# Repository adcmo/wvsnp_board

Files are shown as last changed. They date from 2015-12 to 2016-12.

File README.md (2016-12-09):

# wvsnp_board

What is it?

This is the official board schematic, files, BOM and manufacturer files for the WVSNP Reduced board.

This is the Schematic and PCB layout (including gerber files) for the WVSNP Reduced Carrier Board 
and supporting components.

License and Copyright

This is the official repository of WVSNP Project. All code, SW and Hardware contributed here is 
subject to NDA and agreements you have with the WVSNP Project and ASU.

Quick Start Guide:

NOTE- The following work was done on Ubuntu version 14. Everything should be viewable on Windows or Mac however the 3D viewer will not properly work because of the different directory structures. They will have to be manually changed in KiCAD. 

Questions or concerns: Kevin Virgen kvirgen@gmail.com

1- Download version 4.0.4 of Kicad at http://kicad-pcb.org/download/
Other versions do not work properly with the 3D viewer.

2- Download Wings 3D for 3D model creation at http://www.wings3d.com/

3- Download FreeCAd for 3D model creation at http://www.freecadweb.org/

4- Get a copy of the repository: - Using Command Prompt (Git Bash) git clone 
   //https://github.com/adcmo/wvsnp_board.git
   - Using the GitHub page While logged in to GitHub, there are URLs available 
    in the sidebar: HTTPS clone URL - Using GitHub's GUI to clone repo.

5- Once repo is copied open Kicad - Choose File -> Open Project or CTRL+o - 
   Select "WVSNP_Reduced_board_hand.kicad_pcb.pro" file

   This will open the entire project with all the files necessary to see and 
   edit the schematic and PCB layout. 

3D - To view the board in 3D drag the contents of the folder "add_these_to_packages3d"  and "custom3D" into the "/usr/share/kicad/modules/packages3d" folder.
   This may require root privileges. Then click View -> 3D viewer. If it is still not working 
   you may need to change the permission on the new files because kiCAD seems picky on them.
   Another error may be directory location. If a 3D image of a footprint is not showing up in "3D View" 
   make sure it's pointing to the correct directory by navigation to the footprint's 3D settings menu.  
	- An in Dept tutorial on how to make 3D models is located here
	https://sethkoberg.wordpress.com/2014/03/30/tutorial-custom-3d-models-for-kicad-3d-viewer/
   
6- Making Changes to schematic - Double click on "Board-To-Board.sch" inside the "schematics" folder. 
   This will open the schematic - Make any necessary changes (add/removing 
   components, adding wires, etc) - If any components were added, ensure values 
   are properly filled (see any kicad tutorials) - Once happy with your changes, 
   save it and click the "NET" icon in the tool bar and follow prompts. This step 
   ensures components are populated in PCB side of things. - Run the CvPCB tool 
   to assign footprints for your components and save changes
   - A current video of the 3D model can be seen at :
	https://www.dropbox.com/s/u4em6s6bgvm3ido/WVSNP_Reduced_board.mp4?dl=0

7- Making changes to PCB file - Double click on "WVSNP_Reduced_Board_hand.kicad_pcb" 
   - If components were added, click on "NET" on tool bar and click "Read Current 
     Netlist" This should add all the components you added to the schematic assuming 
     you have footprints available. If you don't have a footprint, look up tutorials 
     on how to create footprints. NOTE: If you assigned an existing footprint and it 
     doesn't populate, check to see if there are warnings after reading the netlist.

   - Once you finished routing all traces and placing all components, save it and run 
     "design rules check" (lady bug on tool bar).
     NOTE: Ensure that the place you are planning to have the boards manufactured 
     support your design rules. Set the design rules before making any changes.

   - Fix any issues that the checker points out. 
   - Save your changes and click "Plot" on toolbar (looks like a printer). Here you'll 
     generate your Gerbers. If you are unsure on what you'd like to add on the Gerbers, 
     look up toturials for generating Gerber files in Kicad. 

BOM

The Revision_BOM is part of the Repo (Excel file). 

Commiting Changes

Follow the same procedures as you would for any files. If using Git Bash, check which 
files have been changed with "git status" or if using GUI, see which files are showing 
in the change window.

Submitting Files for Fabrication

The zipped folder "Fab Files" have everything you need to send it for fabrication. 
Just submit the compressed folder and the shops know what to do with it. If you made 
changes, you'll need to generate new Gerber files and submit those. If you missed any 
important Gerbers (edge cuts for example) the shops will generally ask you for them

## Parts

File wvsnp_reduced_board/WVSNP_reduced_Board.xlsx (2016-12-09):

Column1 | Column2 | Column3 | Column4 | Column5 | Column6 | Column7
Id | Designator | Package | Quantity | Designation | OEM Part # | Notes
DC JACK
1 | C152 | 1206 | 1 | 22uF,±10%, | 490-4739-1-ND (http://www.digikey.com/scripts/DkSearch/dksus.dll?Detail&itemSeq=212905909&uq=636159567750798121) | ceramic
2 | C153 | 603 | 1 | 0.1uF,±10%, | 490-1532-1-ND (http://www.digikey.com/scripts/DkSearch/dksus.dll?Detail&itemSeq=212905998&uq=636159567750798121) | ceramic
3 | Zener | D44 | 1 | 5.1V 1W ±5% | DL4733A-TP (https://www.mouser.com/Search/ProductDetail.aspx)
4 | DCIN | BARREL_JACK | 1 | 2.00mm, DIP | PJ-002A (https://www.mouser.com/Search/ProductDetail.aspx?R=PJ-002Avirtualkey51780000virtualkey490-PJ-002A)
Button
1 | C162 | 603 | 1 | 1uF,±10%, | 0603ZC105KAT2A (https://www.mouser.com/Search/ProductDetail.aspx) | ceramic
2 | RESET1 | TACT SWITCH | 1 |  | PTS645SH50SMTR 92 LFS
DC-DC
1 | C163 | 805 | 1 | 4.7uF,±10%, | GRM21BR61E475KA12L (https://www.mouser.com/Search/ProductDetail.aspx) | ceramic
2 | C164 | 603 | 1 | 1000pF,±10%, | 478-1215-1-ND | ceramic
3 | C165 | 603 | 1 | 1uF,±10%, | 0603ZC105KAT2A (https://www.mouser.com/Search/ProductDetail.aspx) | ceramic
4 | R96 | 603 | 1 | 100kΩ,±1%, | CRCW0603100KFKEA (https://www.mouser.com/Search/ProductDetail.aspx) | ceramic
5 | R97 | 603 | 1 | 330Ω,±1%, | CRCW0603330RFKEA (https://www.mouser.com/Search/ProductDetail.aspx) | ceramic
6 | D1 | 603 | 1 | LED-GRN | LG Q396-PS-35 (https://www.mouser.com/Search/ProductDetail.aspx) | GRN
7 | U1 |  | 1 | MCP1727 | MCP1727-3302E/SN (https://www.mouser.com/Search/ProductDetail.aspx)
RJ45
1 | R1 | 603 | 1 | 0Ω,±5%, | CRCW06030000Z0EA (https://www.mouser.com/Search/ProductDetail.aspx)
2 | R2 | 603 | 1 | 0Ω,±5%, | CRCW06030000Z0EA (https://www.mouser.com/Search/ProductDetail.aspx)
3 | R3 | 603 | 1 | 0Ω,±5%, | CRCW06030000Z0EA (https://www.mouser.com/Search/ProductDetail.aspx)
5 | R4 | 603 | 1 | 0Ω,±5%, | CRCW06030000Z0EA (https://www.mouser.com/Search/ProductDetail.aspx)
6 | R5 | 603 | 1 | 0Ω,±5%, | CRCW06030000Z0EA (https://www.mouser.com/Search/ProductDetail.aspx)
7 | R6 | 603 | 1 | 0Ω,±5%, | CRCW06030000Z0EA (https://www.mouser.com/Search/ProductDetail.aspx)
8 | R7 | 603 | 1 | 0Ω,±5%, | CRCW06030000Z0EA (https://www.mouser.com/Search/ProductDetail.aspx)
9 | R8 | 603 | 1 | 0Ω,±5%, | CRCW06030000Z0EA (https://www.mouser.com/Search/ProductDetail.aspx)
10 | R9 | 603 | 1 | 0Ω,±5%, | CRCW06030000Z0EA (https://www.mouser.com/Search/ProductDetail.aspx)
11 | R10 | 603 | 1 | 330Ω,±1%, | CRCW0603330RFKEA (https://www.mouser.com/Search/ProductDetail.aspx)
12 | R11 | 603 | 1 | 0Ω,±5%, | CRCW06030000Z0EA (https://www.mouser.com/Search/ProductDetail.aspx)
13 | R12 | 603 | 1 | 330Ω,±1%, | CRCW0603330RFKEA (https://www.mouser.com/Search/ProductDetail.aspx)
14 | R13 | 603 | 1 | 10Ω,±1%, | CRCW060310R0FKEA (https://www.mouser.com/Search/ProductDetail.aspx)
15 | C1 | 603 | 1 | 1000pF,±10%, | 478-1215-1-ND | ceramic
16 | C2 | 603 | 1 | 0.1uF,±10%,16V | 490-1532-1-ND (http://www.digikey.com/scripts/DkSearch/dksus.dll?Detail&itemSeq=212905998&uq=636159567750798121) | ceramic
17 | LAN1 |  | 1 | RT7-174AAM1A | SI-61001-F
EDM_HEADER
1 | J1 |  | 1 | EDM_HEADER | AS0B821-S55B-7H
2 | R386 | 603 | 1 | 0Ω,±5%, | CRCW06030000Z0EA (https://www.mouser.com/Search/ProductDetail.aspx)

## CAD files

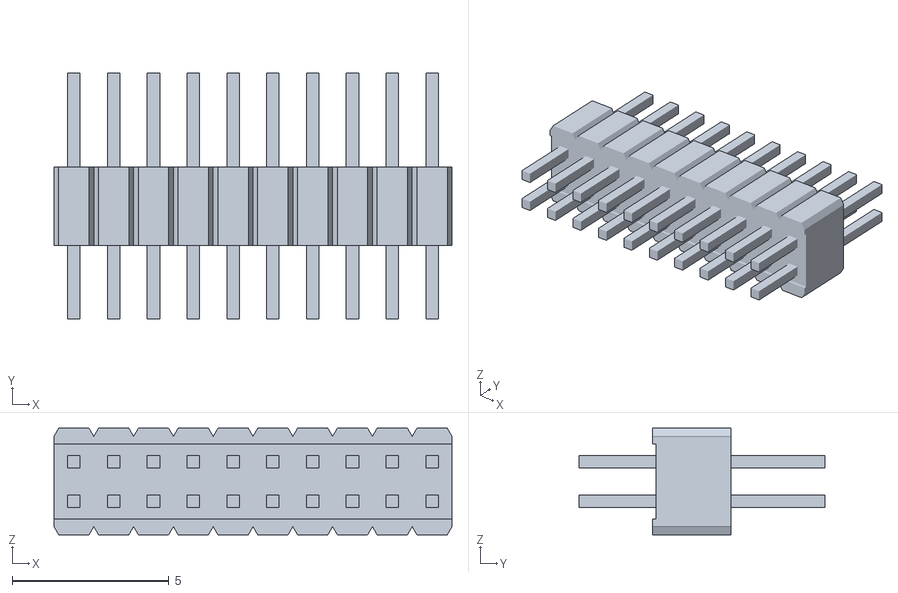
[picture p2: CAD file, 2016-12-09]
wvsnp_reduced_board/custom3d/pin_hole_10x2_127_3d.obj
12.7 x 7.85 x 3.40

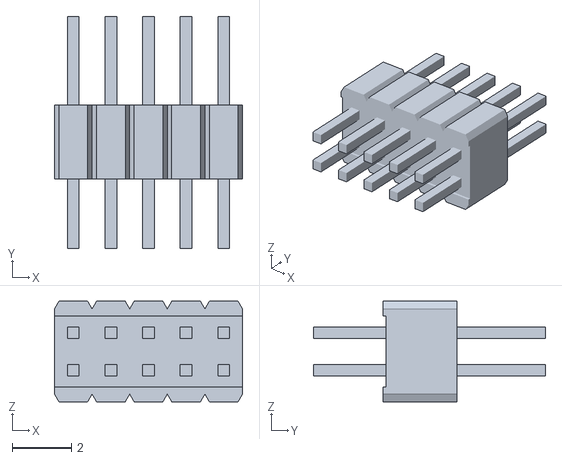
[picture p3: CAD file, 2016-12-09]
wvsnp_reduced_board/custom3d/pin_hole_2x4_3d.obj
6.35 x 7.85 x 3.40

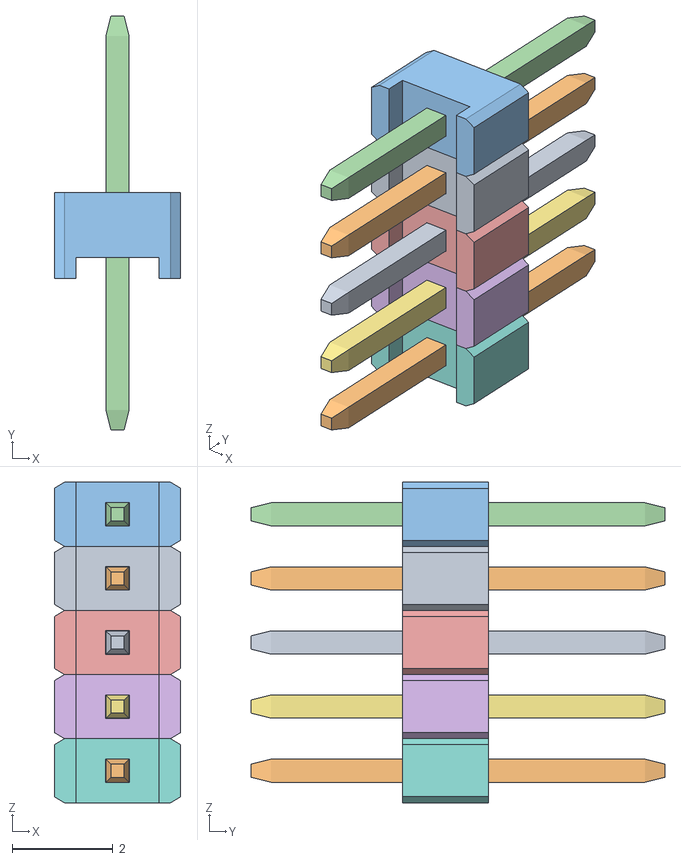
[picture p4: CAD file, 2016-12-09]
wvsnp_reduced_board/custom3d/pin_hole_1x5_127_3d.obj
2.50 x 8.20 x 6.35
BD020Pin-8.2mm004
BD020Pin-8.2mm001
BB020-insG002
BD020Pin-8.2mm002
BB020-insG004
BB020-insG
BD020Pin-8.2mm
BB020-insG001
BB020-insG003
BD020Pin-8.2mm003

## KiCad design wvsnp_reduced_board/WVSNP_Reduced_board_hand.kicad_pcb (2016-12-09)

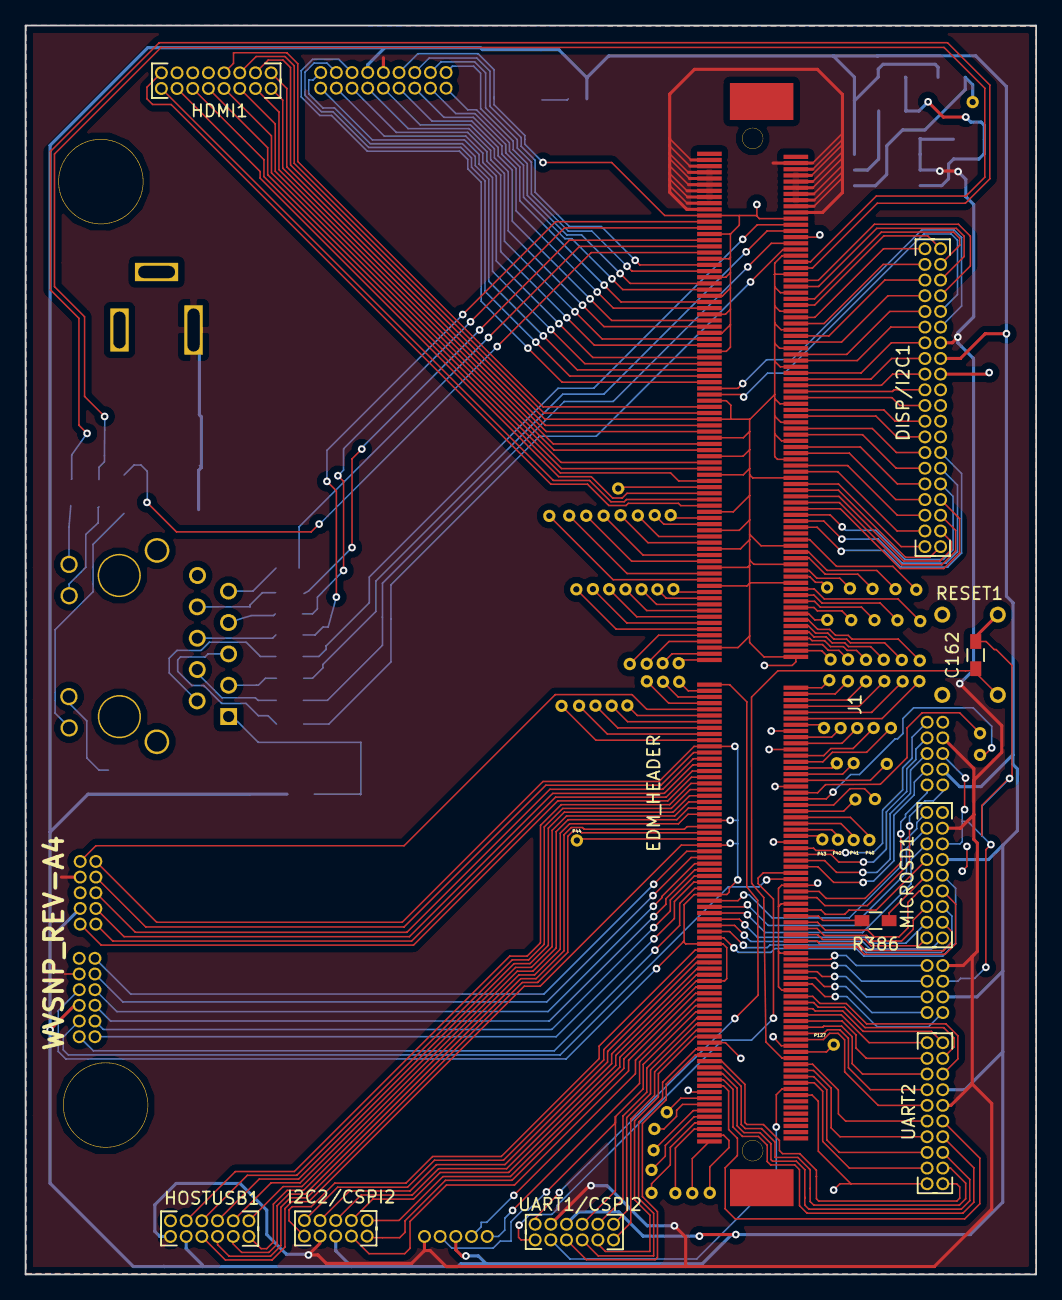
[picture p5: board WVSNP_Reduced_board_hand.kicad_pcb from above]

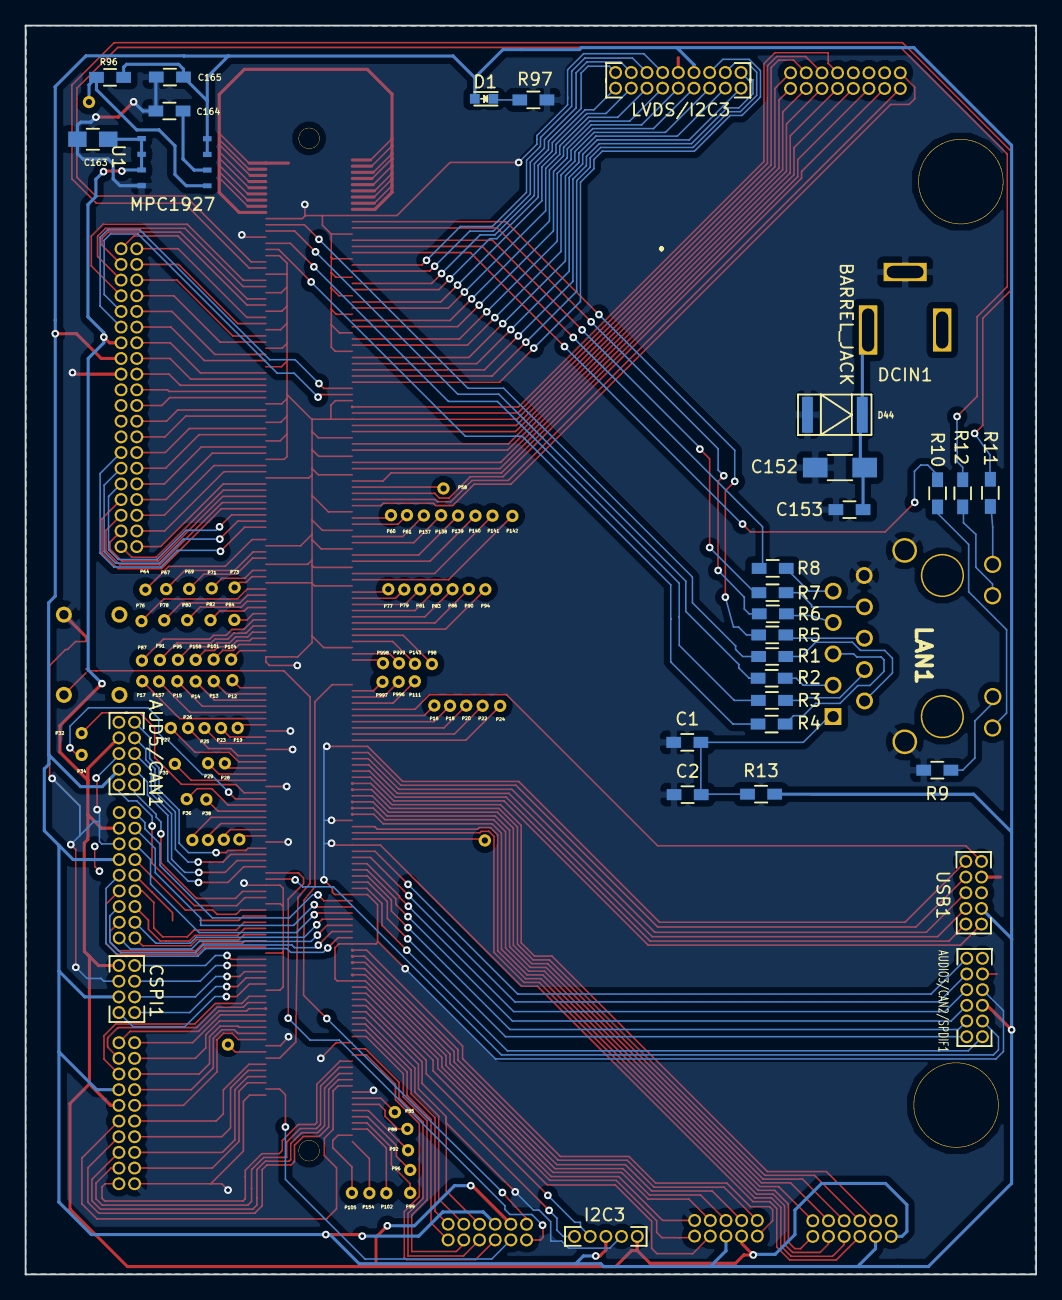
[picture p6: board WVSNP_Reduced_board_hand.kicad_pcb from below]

Board: 4 copper layers, 81.9 x 101.2 mm, 120 parts (103 on the bottom side), 247 nets.

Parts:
AUD5/CAN1: CONN_10; Pin_Header_Straight_2x5_127
AUDIO3/CAN2/SPDIF1: CONN_12; Pin_Header_Straight_2x6_127
C1: 1000P; R_0603_HandSoldering
C2: 0.1u; R_0603_HandSoldering
C152: 22u; C_1206_HandSoldering
C153: 4.7u; R_0603_HandSoldering
C162: .22U; R_0603_HandSoldering
C163: 4.7u; C_0805_HandSoldering
C164: 1n; R_0603_HandSoldering
C165: 11u; R_0603_HandSoldering
CSPI1: CONN_8; Pin_Header_Straight_2x4_127
D1: LED; LED-0603
D44: ZENER; SM0603
DCIN1: BARREL_JACK; Wand_DC_Jack
DISP/I2C1: CONN_40; Pin_Header_Straight_2x20_127
HDMI1: CONN_16; Pin_Header_Straight_2x8_127
HOSTUSB1: CONN_12; Pin_Header_Straight_2x6_127
I2C2/CSPI2: CONN_10; Pin_Header_Straight_2x5_127
I2C3: CONN_5; Pin_Header_Straight_1x5_127
J1: EDM_HEADER; EDM_HEADER_MXM3.0
LAN1: RT7-174AAM1A; WAND_RJ45_TRANSFO
LVDS/I2C3: CONN_18; Pin_Header_Straight_2x8_127
MICROSD1: CONN_18; Pin_Header_Straight_2x8_127
P12, P13, P14, P15, P16, P17, P18, P19, P20, P22, P23, P24, P25, P26, P27, P28, P29, P30, P32, P34, P36, P38, P40, P41, P42, P43, P44, P58, P60, P61, P64, P67, P69, P71, P73, P76, P77, P78, P79, P80, P81, P82, P83, P84, P85, P86, P87, P88, P90, P91, P92, P94, P95, P96, P98, P99, P101, P102, P104, P105, P111, P127, P137, P138, P139, P140, P141, P142, P143, P154, P157, P158, P996, P997, P998, P999: TST; TEST_POINT
R1, R2, R3, R4, R5, R6, R7, R8, R9, R11, R386: 0; R_0603_HandSoldering
R10, R12, R97: 330; R_0603_HandSoldering
R13: 10; R_0603_HandSoldering
R96: 6.04k; R_0603_HandSoldering
RESET1: SW_PUSH; Wand_Push_button
U1: MPC1927; Wand_AME_8816
UART1/CSPI2: CONN_12; Pin_Header_Straight_2x6_127
UART2: CONN_20; Pin_Header_Straight_2x10_127
USB1: CONN_10; Pin_Header_Straight_2x5_127

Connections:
+3.3V: AUD5/CAN1.9, AUDIO3/CAN2/SPDIF1.9, C165.1, CSPI1.3, D1.2, DISP/I2C1.33, HOSTUSB1.8, I2C2/CSPI2.8, I2C3.3, LVDS/I2C3.13, MICROSD1.15, R13.2, R96.2, U1.7, U1.8, UART1/CSPI2.4, UART2.17, USB1.7
+5V: AUD5/CAN1.7, AUDIO3/CAN2/SPDIF1.11, C152.1, C153.1, C163.1, CSPI1.1, D44.2, DCIN1.1, DISP/I2C1.34, HOSTUSB1.7, I2C2/CSPI2.7, I2C3.5, J1.E1_2, J1.E1_3, J1.E1_4, J1.E1_5, J1.E1_6, J1.E1_7, J1.E1_8, J1.E1_9, J1.E2_2, J1.E2_3, J1.E2_4, J1.E2_5, J1.E2_6, J1.E2_7, J1.E2_8, J1.E2_9, J1.E110, J1.E210, LVDS/I2C3.14, MICROSD1.17, U1.1, U1.2, U1.3, UART1/CSPI2.5, UART2.16, USB1.9
/EXCDA_nPREST: J1.107, P81.1
/GND_DRAIN1: J1.147, P20.1
/HDMI1_CAD: J1.69, P58.1
/MNF7: J1.267, P85.1
/MNF8: J1.269, P88.1
/MNF9: J1.271, P92.1
/MNF10: J1.273, P96.1
/MNF11: J1.275, P99.1
/MNF12: J1.277, P102.1
/MNF13_WATCHDOG: J1.279, P105.1
/PCIEA_CLKN: J1.87, P138.1
/PCIEA_CLKP: J1.85, P137.1
/PCIEA_RXN: J1.99, P142.1
/PCIEA_RXP: J1.97, P141.1
/PCIEA_TXN: J1.93, P140.1
/PCIEA_TXP: J1.91, P139.1
/PCIEB_CLKN: J1.81, P61.1
/PCIEB_CLKP: J1.79, P60.1
/PCIEB_RXN: J1.111, P86.1
/PCIEB_RXP: J1.109, P83.1
/PCIEB_TXN: J1.105, P79.1
/PCIEB_TXP: J1.103, P77.1
/PCIE_CLK_OEA: J1.113, P90.1
/PCIE_CLK_OEB: J1.115, P94.1
/PCIE_nRST: J1.119, P143.1
/PCIE_nWAKE: J1.117, P98.1
/PWR_BTN: J1.252, P127.1
/RSVD1: J1.114, P91.1
/R_NANDF_A1: J1.144, P17.1
/R_NANDF_A2: J1.142, P157.1
/R_NANDF_A3: J1.140, P15.1
/R_NANDF_A4: J1.138, P14.1
/R_NANDF_A5: J1.136, P13.1
/R_NANDF_A6: J1.134, P12.1
/R_NANDF_A7: J1.122, P104.1
/R_NANDF_A8: J1.120, P101.1
/R_NANDF_A9: J1.118, P158.1
/R_NANDF_A10: J1.116, P95.1
/R_NANDF_ALE: J1.108, P82.1
/R_NANDF_CLE: J1.106, P80.1
/R_NANDF_CS0: J1.86, P64.1
/R_NANDF_CS1: J1.90, P67.1
/R_NANDF_CS2: J1.92, P69.1
/R_NANDF_CS3: J1.96, P71.1
/R_NANDF_CS4: J1.98, P73.1
/R_NANDF_D0: J1.182, P43.1
/R_NANDF_D1: J1.180, P42.1
/R_NANDF_D2: J1.178, P41.1
/R_NANDF_D3: J1.176, P40.1
/R_NANDF_D4: J1.174, P38.1
/R_NANDF_D5: J1.172, P36.1
/R_NANDF_D6: J1.170, P34.1
/R_NANDF_D7: J1.168, P32.1
/R_NANDF_D8: J1.164, P30.1
/R_NANDF_D9: J1.162, P29.1
/R_NANDF_D10: J1.160, P28.1
/R_NANDF_D11: J1.158, P27.1
/R_NANDF_D12: J1.156, P26.1
/R_NANDF_D13: J1.152, P25.1
/R_NANDF_D14: J1.150, P23.1
/R_NANDF_D15: J1.146, P19.1
/R_NANDF_RB0: J1.102, P76.1
/R_NANDF_RE: J1.112, P87.1
/R_NANDF_WE: J1.110, P84.1
/R_NANDF_WP: J1.104, P78.1
/SATA1_RXN: J1.125, P998.1
/SATA1_RXP: J1.123, P999.1
/SATA1_TXN: J1.137, P996.1
/SATA1_TXP: J1.135, P997.1
/StdB1_SSRXN: J1.145, P18.1
/StdB1_SSRXP: J1.143, P16.1
/StdB1_SSTXN: J1.151, P24.1
/StdB1_SSTXP: J1.149, P22.1
/USB_H1_VBUS: J1.183, P44.1
/USB_HUB_RESET_B: J1.139, P111.1
/VCC_RTC: J1.281, P154.1
AUD3_RXD: AUDIO3/CAN2/SPDIF1.1, J1.187
AUD3_TXC: AUDIO3/CAN2/SPDIF1.4, J1.193
AUD3_TXD: AUDIO3/CAN2/SPDIF1.3, J1.191
AUD3_TXFS: AUDIO3/CAN2/SPDIF1.2, J1.189
AUD5_RXD: AUD5/CAN1.5, J1.186
AUD5_TXC: AUD5/CAN1.2, J1.192
AUD5_TXD: AUD5/CAN1.3, J1.190
AUD5_TXFS: AUD5/CAN1.4, J1.188
AUDIO_CLK: AUDIO3/CAN2/SPDIF1.5, J1.195
AUX_5V_EN: J1.257, UART2.12
CAN1n: AUD5/CAN1.10, J1.202
CAN1p: AUD5/CAN1.1, J1.200
CAN2n: AUDIO3/CAN2/SPDIF1.7, J1.199
CAN2p: AUDIO3/CAN2/SPDIF1.6, J1.197
CSPI1_CS0: CSPI1.5, J1.228
CSPI1_CS1: CSPI1.4, J1.230
CSPI1_MISO: CSPI1.7, J1.224
CSPI1_MOSI: CSPI1.8, J1.222
CSPI1_SCLK: CSPI1.6, J1.226
CSPI2_CS0: I2C2/CSPI2.3, J1.225
CSPI2_CS1: I2C2/CSPI2.2, J1.227
CSPI2_MISO: I2C2/CSPI2.5, J1.221
CSPI2_MOSI: I2C2/CSPI2.6, J1.219
CSPI2_SCLK: I2C2/CSPI2.4, J1.223
DDC_SCL: HDMI1.9, J1.73
DDC_SDA: HDMI1.8, J1.75
DISP0_BKLEN: DISP/I2C1.27, J1.82
DISP0_CLK: DISP/I2C1.21, J1.70
DISP0_CNTRST: DISP/I2C1.24, J1.76
DISP0_DAT0: DISP/I2C1.37, J1.2
DISP0_DAT1: DISP/I2C1.38, J1.4
DISP0_DAT2: DISP/I2C1.39, J1.8
DISP0_DAT3: DISP/I2C1.40, J1.10
DISP0_DAT4: DISP/I2C1.1, J1.14
DISP0_DAT5: DISP/I2C1.2, J1.16
DISP0_DAT6: DISP/I2C1.3, J1.20
DISP0_DAT7: DISP/I2C1.4, J1.22
DISP0_DAT8: DISP/I2C1.5, J1.26
DISP0_DAT9: DISP/I2C1.6, J1.28
DISP0_DAT10: DISP/I2C1.7, J1.32
DISP0_DAT11: DISP/I2C1.8, J1.34
DISP0_DAT12: DISP/I2C1.9, J1.36
DISP0_DAT13: DISP/I2C1.10, J1.38
DISP0_DAT14: DISP/I2C1.11, J1.40
DISP0_DAT15: DISP/I2C1.12, J1.44
DISP0_DAT16: DISP/I2C1.13, J1.46
DISP0_DAT17: DISP/I2C1.14, J1.50
DISP0_DAT18: DISP/I2C1.15, J1.52
DISP0_DAT19: DISP/I2C1.16, J1.56
DISP0_DAT20: DISP/I2C1.17, J1.58
DISP0_DAT21: DISP/I2C1.18, J1.62
DISP0_DAT22: DISP/I2C1.19, J1.64
DISP0_DAT23: DISP/I2C1.20, J1.68
DISP0_DRDY: DISP/I2C1.25, J1.78
DISP0_HSYNC: DISP/I2C1.22, J1.72
DISP0_VDDEN: DISP/I2C1.26, J1.80
DISP0_VSYNC: DISP/I2C1.23, J1.74
ETHER1_D0N: J1.E4_3, R2.1
ETHER1_D0P: J1.E4_2, R1.1
ETHER1_D1N: J1.E4_6, R4.1
ETHER1_D1P: J1.E4_5, R3.1
ETHER1_D2N: J1.E3_3, R6.1
ETHER1_D2P: J1.E3_2, R5.1
ETHER1_D3N: J1.E3_6, R8.1
ETHER1_D3P: J1.E3_5, R7.1
GND: AUD5/CAN1.8, AUDIO3/CAN2/SPDIF1.10, C1.1, C2.1, C152.2, C153.2, C162.2, C163.2, C164.2, C165.2, CSPI1.2, D44.1, DCIN1.3, DISP/I2C1.32, HDMI1.2, HOSTUSB1.9, I2C2/CSPI2.1, I2C3.4, J1.1, J1.6, J1.7, J1.12, J1.13, J1.18, J1.19, J1.24, J1.25, J1.30, J1.41, J1.42, J1.47, J1.48, J1.53, J1.54, J1.59, J1.60, J1.65, J1.66, J1.77, J1.83, J1.88, J1.89, J1.94, J1.95, J1.100, J1.101, J1.121, J1.124, J1.148, J1.153, J1.154, J1.166, J1.177, J1.184, J1.185, J1.198, J1.201, J1.204, J1.217, J1.220, J1.229, J1.232, J1.239, J1.249, J1.250, J1.265, J1.266, J1.E3_1, J1.E3_4, J1.E3_8, J1.E4_1, J1.E4_4, J1.E4_7, J1.E410, LAN1.10, LAN1.H1, LAN1.H2, LVDS/I2C3.15, MICROSD1.16, R9.2, R97.2, RESET1.1, U1.4, UART1/CSPI2.3, UART2.10, USB1.1
GND_DRAIN2: HOSTUSB1.2, J1.171
GPIO1_24: J1.262, UART2.9
GPIO3_8: J1.261, UART2.14
GPIO3_11: J1.256, UART2.6
GPIO3_12: J1.255, UART2.11
GPIO3_26: J1.259, UART2.13
GPIO3_27: J1.258, UART2.7
GPIO6_1: J1.133, UART1/CSPI2.6
GPIO6_31: J1.260, UART2.8
GPIO7_8: J1.264, UART1/CSPI2.8
GPIO_1_CLK0: J1.194, UART1/CSPI2.7
GPIO_19: J1.263, UART2.15
HDMI1_CEC: HDMI1.10, J1.71
HDMI1_HPD: HDMI1.11, J1.67
HDMI_CLKM: HDMI1.3, J1.45
HDMI_CLKP: HDMI1.4, J1.43
HDMI_D0M: HDMI1.16, J1.51
HDMI_D0P: HDMI1.1, J1.49
HDMI_D1M: HDMI1.14, J1.57
HDMI_D1P: HDMI1.15, J1.55
HDMI_D2M: HDMI1.12, J1.63
HDMI_D2P: HDMI1.13, J1.61
I2C1_SCL: DISP/I2C1.36, J1.39
I2C1_SDA: DISP/I2C1.35, J1.37
I2C2_SCL: I2C2/CSPI2.10, J1.231
I2C2_SDA: I2C2/CSPI2.9, J1.233
I2C3_SCL: I2C3.2, J1.235
I2C3_SDA: I2C3.1, J1.237
LED1_ACT: J1.E3_7, R10.2
LED1_nLINK100: J1.E4_8, R12.2
LED1_nLINK1000: J1.E4_9, R11.2
LVDS0_BLT_CTRL: J1.27, LVDS/I2C3.8
LVDS0_CLK_N: J1.21, LVDS/I2C3.6
LVDS0_CLK_P: J1.23, LVDS/I2C3.7
LVDS0_EN: J1.29, LVDS/I2C3.9
LVDS0_TX0_N: J1.E3_9, LVDS/I2C3.16
LVDS0_TX0_P: J1.E310, LVDS/I2C3.17
LVDS0_TX1_N: J1.3, LVDS/I2C3.18
LVDS0_TX1_P: J1.5, LVDS/I2C3.1
LVDS0_TX2_N: J1.9, LVDS/I2C3.2
LVDS0_TX2_P: J1.11, LVDS/I2C3.3
LVDS0_TX3_N: J1.15, LVDS/I2C3.4
LVDS0_TX3_P: J1.17, LVDS/I2C3.5
LVDS0_VDDEN: J1.31, LVDS/I2C3.10
unnamed: D1.1, R97.1
unnamed: C164.1, R96.1, U1.5, U1.6
unnamed: LAN1.5, R4.2
unnamed: LAN1.4, R3.2
unnamed: LAN1.3, R2.2
unnamed: LAN1.2, R1.2
unnamed: LAN1.9, R8.2
unnamed: LAN1.8, R7.2
unnamed: LAN1.7, R6.2
unnamed: LAN1.6, R5.2
unnamed: LAN1.L1, R9.1
unnamed: LAN1.L4, R12.1
unnamed: LAN1.L3, R11.1
unnamed: LAN1.L2, R10.1
unnamed: C1.2, C2.2, LAN1.1, R13.1
S3: J1.251, UART1/CSPI2.10
S5: J1.253, UART1/CSPI2.9
SD1_CD: J1.203, MICROSD1.1
SD1_CLK: J1.206, MICROSD1.4
SD1_CMD: J1.205, MICROSD1.2
SD1_DATA0: J1.212, MICROSD1.7
SD1_DATA1: J1.209, MICROSD1.8
SD1_DATA2: J1.214, MICROSD1.9
SD1_DATA3: J1.211, MICROSD1.10
SD1_DATA4: J1.216, MICROSD1.11
SD1_DATA5: J1.213, MICROSD1.12
SD1_DATA6: J1.218, MICROSD1.13
SD1_DATA7: J1.215, MICROSD1.14
SD1_LED: J1.208, MICROSD1.5, R386.1, R386.2
SD1_PWREN: J1.210, MICROSD1.6
SD1_WP: J1.207, MICROSD1.3
SPDIF_OUT: AUDIO3/CAN2/SPDIF1.8, J1.196
StdB2_SSRXN: HOSTUSB1.3, J1.169
StdB2_SSRXP: HOSTUSB1.4, J1.167
StdB2_SSTXN: HOSTUSB1.12, J1.175
StdB2_SSTXP: HOSTUSB1.1, J1.173
UART1_CTS: J1.241, UART1/CSPI2.2
UART1_RTS: J1.247, UART1/CSPI2.11
UART1_RXD: J1.245, UART1/CSPI2.12
UART1_TXD: J1.243, UART1/CSPI2.1
UART2_CTS: J1.234, UART2.18
UART2_DCD: J1.242, J1.248, UART2.2, UART2.5
UART2_DSR: J1.244, UART2.3
UART2_DTR: J1.246, UART2.4
UART2_RTS: J1.240, UART2.1
UART2_RXD: J1.238, UART2.20
UART2_TXD: J1.236, UART2.19
USB_H1_OC: HOSTUSB1.5, J1.165
USB_HOST_DN: HOSTUSB1.11, J1.179
USB_HOST_DP: HOSTUSB1.10, J1.181
USB_OTG_DN: J1.159, USB1.4
USB_OTG_DP: J1.157, USB1.3
USB_OTG_ID: J1.155, USB1.2
USB_OTG_OC: J1.141, USB1.10
USB_OTG_PWR_EN: J1.163, USB1.6
USB_OTG_VBUS: J1.161, USB1.5
eDP0_HPD: J1.35, LVDS/I2C3.12
eDP0_SELF_TEST: J1.33, LVDS/I2C3.11
nRESET_BTN: C162.1, J1.254, RESET1.2

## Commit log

2015-11-12 initial push
    [Board-To-Board.sch, WVSNP Reduced Board.kicad_REV4_pcb.kicad_pcb, WVSNP Reduced Board.kicad_REV5_pcb.kicad_pcb]
2015-12-03 start over
    [Board-To-Board.sch]
